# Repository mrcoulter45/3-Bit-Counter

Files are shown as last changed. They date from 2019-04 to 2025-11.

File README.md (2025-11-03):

# 3-Bit Counter
This is a 3-bit counter project I made because I was interested in trying my hand at a custon PCB. The PCB was made by JLCPCB, and turned out really good. The counter operates via NAND and D flip-flop ICs, the Arduino Nano is used simply for a clk signal to the chips. 
The 3-bit counter consists of:
- x4 MH7420 (SN7420N / NTE7420) DUAL 4-INPUT NAND 7420 ICs
- x2 CD4013B CMOS Dual D-Type Flip-Flop ICs
- x1 Arduino Nano
- x3 5mm blue LEDs
- x3 220Ω resistors
- x2 10nf monolithic capacitors
- x2 100nf monolithic capacitors
- PCB


  
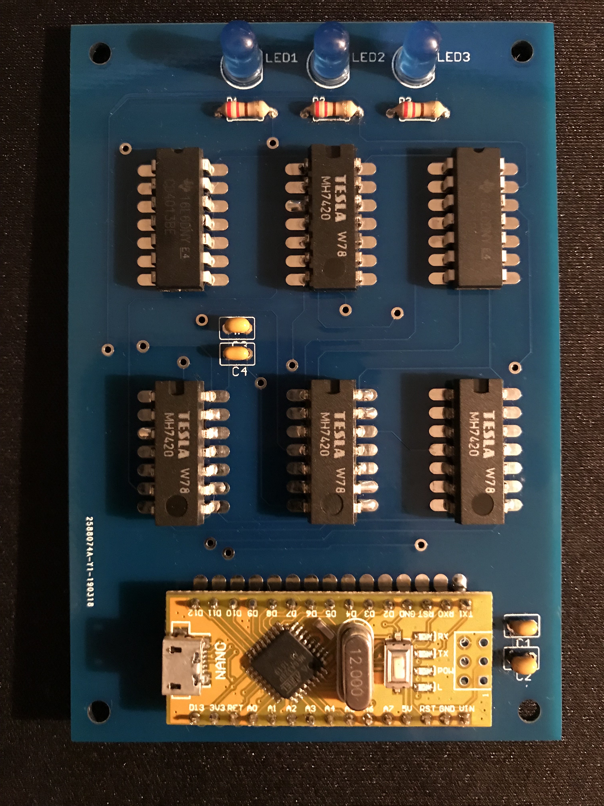
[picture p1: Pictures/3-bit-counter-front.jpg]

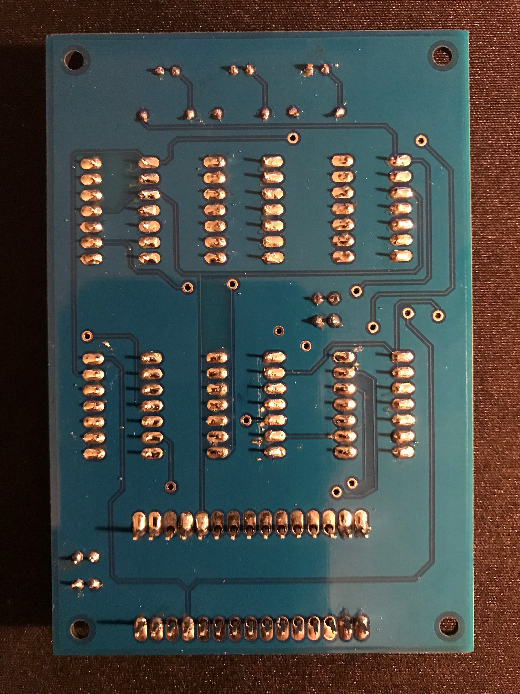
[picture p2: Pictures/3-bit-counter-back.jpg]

  
__________
  
## 3-Bit Counter v1
Here is the first version of the counter that I made with a PCB milling machine. It was much more difficult to make, in that I had to solder every pin on both sides of the PCB, as well as solder wires to both sides of the PCB for every via. It doesn't work so well because it doesn't have capacitors and the copper became very corroded over time.  
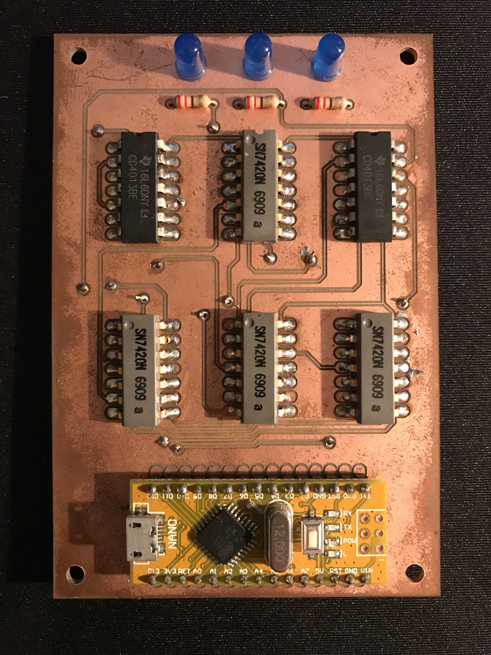
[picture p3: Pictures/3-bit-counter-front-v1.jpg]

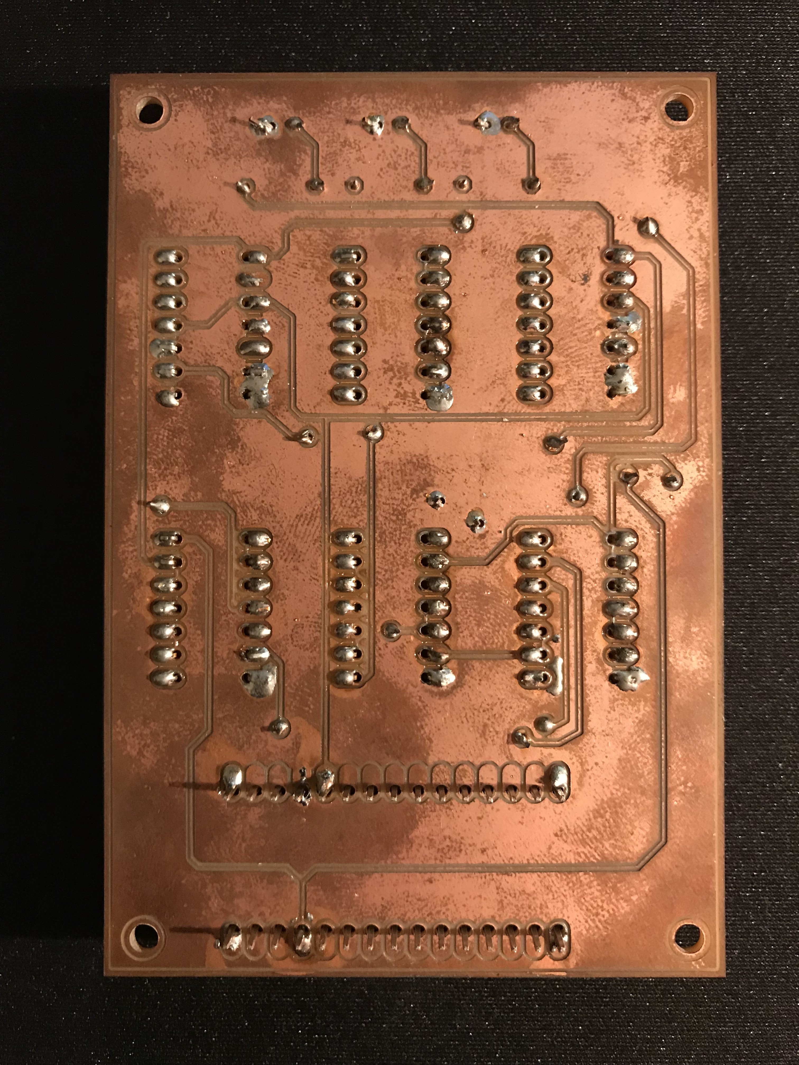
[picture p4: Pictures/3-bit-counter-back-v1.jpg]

__________  

---

## 🎥 Video of 3-Bit Counter Logic Circuit

<p align="center">
  <a href="https://youtu.be/tnVruFOkVYI" target="_blank" style="text-decoration:none;">
    <span style="position: relative; display: inline-block;">
      YouTube video thumbnail
  </a>
</p>

---

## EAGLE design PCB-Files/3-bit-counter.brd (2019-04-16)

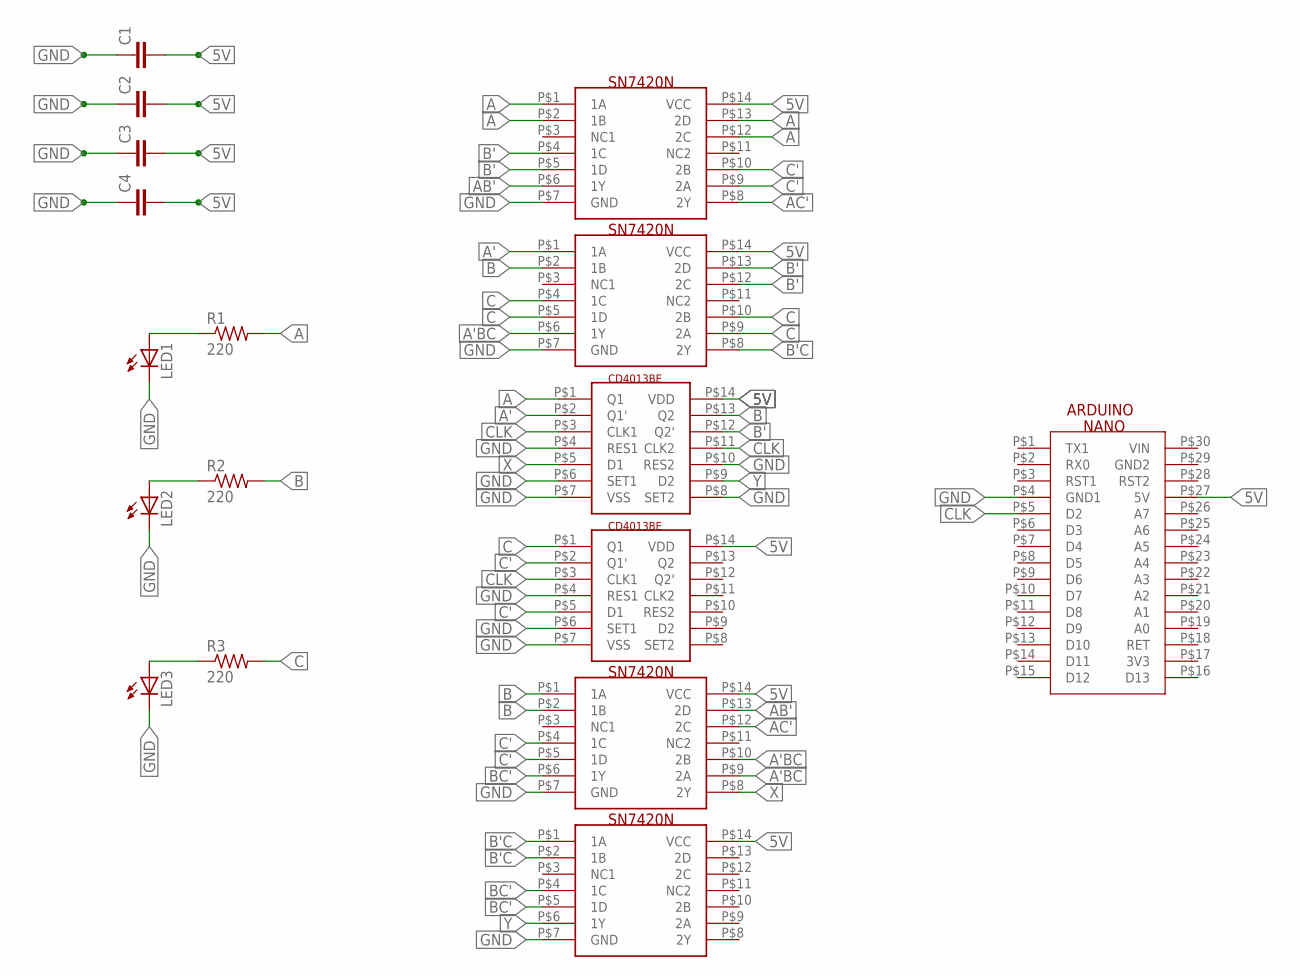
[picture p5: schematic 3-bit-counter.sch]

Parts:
C1, C2, C3, C4: C2,5-3; C2.5-3
DFF1, DFF2: MC_DFFDIP14; DIP14
LED1, LED2, LED3: LED5MM
NAND1, NAND2, NAND3, NAND4: MC_NANDDIP14; DIP14
R1, R2, R3: 220; 0204/7
U$7: MC_NANO

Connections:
5V: C1.2, C2.2, C3.2, C4.2, DFF1.P$14 (VDD), DFF2.P$14 (VDD), NAND1.P$14 (VCC), NAND2.P$14 (VCC), NAND3.P$14 (VCC), NAND4.P$14 (VCC), U$7.P$27 (5V)
A: DFF1.P$1 (Q1), NAND1.P$1 (1A), NAND1.P$2 (1B), NAND1.P$12 (2C), NAND1.P$13 (2D), R1.2
A': DFF1.P$2 (Q1'), NAND2.P$1 (1A)
A'BC: NAND2.P$6 (1Y), NAND3.P$9 (2A), NAND3.P$10 (2B)
AB': NAND1.P$6 (1Y), NAND3.P$13 (2D)
AC': NAND1.P$8 (2Y), NAND3.P$12 (2C)
B: DFF1.P$13 (Q2), NAND2.P$2 (1B), NAND3.P$1 (1A), NAND3.P$2 (1B), R2.2
B': DFF1.P$12 (Q2'), NAND1.P$4 (1C), NAND1.P$5 (1D), NAND2.P$12 (2C), NAND2.P$13 (2D)
B'C: NAND2.P$8 (2Y), NAND4.P$1 (1A), NAND4.P$2 (1B)
BC': NAND3.P$6 (1Y), NAND4.P$4 (1C), NAND4.P$5 (1D)
C: DFF2.P$1 (Q1), NAND2.P$4 (1C), NAND2.P$5 (1D), NAND2.P$9 (2A), NAND2.P$10 (2B), R3.2
C': DFF2.P$2 (Q1'), DFF2.P$5 (D1), NAND1.P$9 (2A), NAND1.P$10 (2B), NAND3.P$4 (1C), NAND3.P$5 (1D)
CLK: DFF1.P$3 (CLK1), DFF1.P$11 (CLK2), DFF2.P$3 (CLK1), U$7.P$5 (D2)
GND: C1.1, C2.1, C3.1, C4.1, DFF1.P$4 (RES1), DFF1.P$6 (SET1), DFF1.P$7 (VSS), DFF1.P$8 (SET2), DFF1.P$10 (RES2), DFF2.P$4 (RES1), DFF2.P$6 (SET1), DFF2.P$7 (VSS), LED1.K (C), LED2.K (C), LED3.K (C), NAND1.P$7 (GND), NAND2.P$7 (GND), NAND3.P$7 (GND), NAND4.P$7 (GND), U$7.P$4 (GND1)
unnamed: LED3.A, R3.1
unnamed: LED2.A, R2.1
unnamed: LED1.A, R1.1
X: DFF1.P$5 (D1), NAND3.P$8 (2Y)
Y: DFF1.P$9 (D2), NAND4.P$6 (1Y)

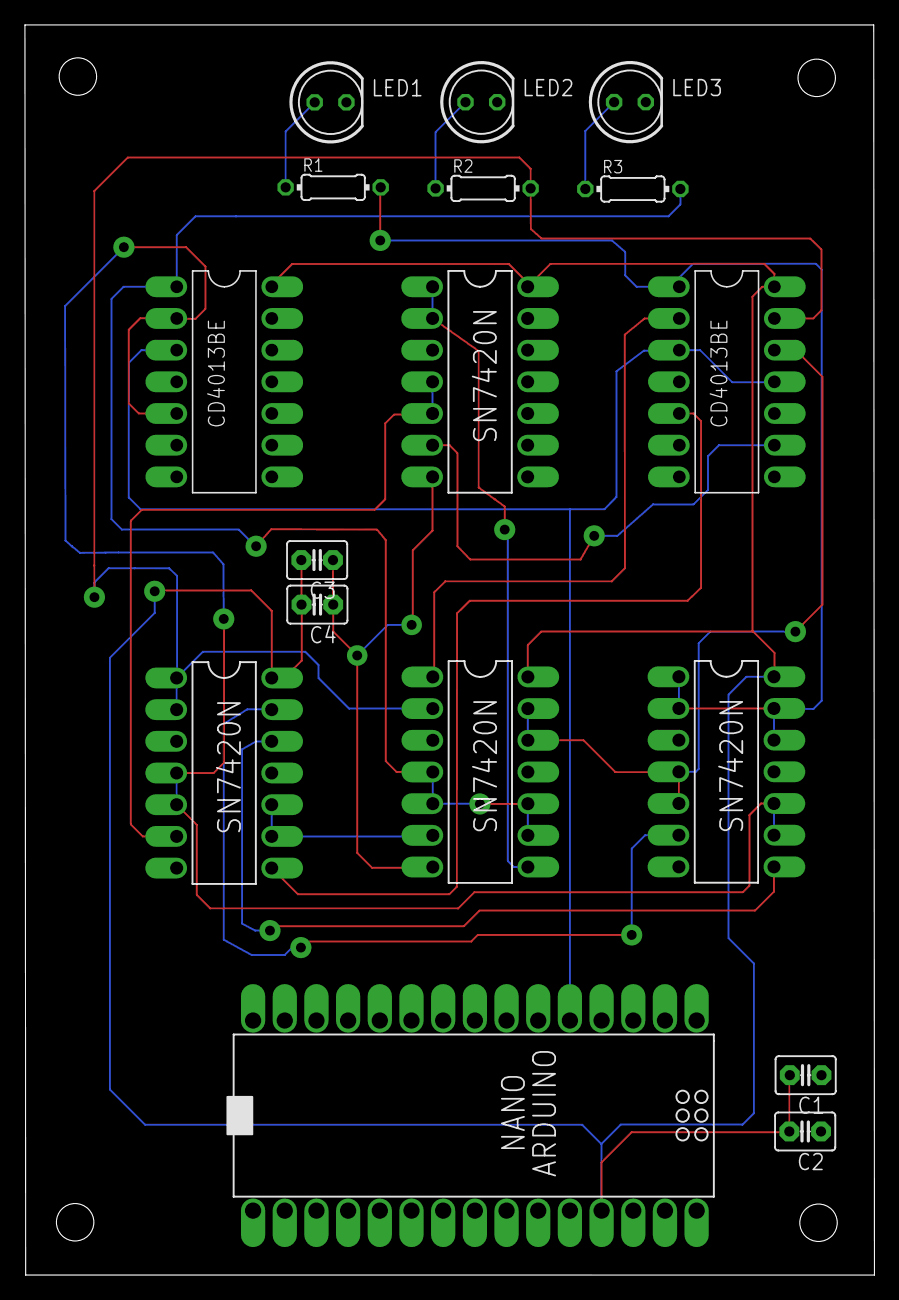
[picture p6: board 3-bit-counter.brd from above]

Board: 2 copper layers, 68.1 x 100.2 mm, 17 parts (0 on the bottom side), 19 nets.

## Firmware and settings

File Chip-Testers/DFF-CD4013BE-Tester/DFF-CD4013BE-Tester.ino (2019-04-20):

void setup() {
    pinMode(2, OUTPUT);//clk
    pinMode(3, OUTPUT);//D1
    pinMode(4, OUTPUT);//D2
}

void loop() {
    while (1) {
        digitalWrite(2, 0);
        digitalWrite(3, 0);
        digitalWrite(4, 0);
        delay(500);
        digitalWrite(2, 1);
        delay(500);
        digitalWrite(2, 0);
        digitalWrite(3, 1);
        digitalWrite(4, 1);
        delay(500);
        digitalWrite(2, 1);
        delay(500);
    }
}

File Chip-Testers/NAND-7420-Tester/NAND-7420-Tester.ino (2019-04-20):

void setup() {
    Serial.begin(9600);
    pinMode(2, OUTPUT);
    pinMode(3, OUTPUT);
    pinMode(4, OUTPUT);
    pinMode(5, OUTPUT);
    pinMode(6, OUTPUT);
    pinMode(7, OUTPUT);
    pinMode(8, OUTPUT);
    pinMode(9, OUTPUT);
}

void loop() {
    for (uint8_t i = 0; i < 16; i += 1) {
        digitalWrite(2, (i & 1));
        digitalWrite(3, (i & 2) >> 1);
        digitalWrite(4, (i & 4) >> 2);
        digitalWrite(5, (i & 8) >> 3);
        digitalWrite(6, (i & 1));
        digitalWrite(7, (i & 2) >> 1);
        digitalWrite(8, (i & 4) >> 2);
        digitalWrite(9, (i & 8) >> 3);
        Serial.println(i);
        delay(300);
    }
}
